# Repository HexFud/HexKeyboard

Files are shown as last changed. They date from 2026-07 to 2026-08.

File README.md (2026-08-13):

# 9-key macropad + encoder + OLED

Homemade macropad: 9 keys in a 3x3 grid, a rotary encoder, and a 0.91" OLED screen. Every switch has its own RGB LED for backlighting, all chained together on a single data pin.

## Hardware

- Seeed XIAO RP2040
- 0.91 inch OLED display
- Rotary encoder with built-in push button
- 9x MX-Style switches, each with its own 1N4148 diode, 3x3 matrix
- 9x SK6812MINI-E LEDs daisy-chained for per-key backlighting

## Schematic

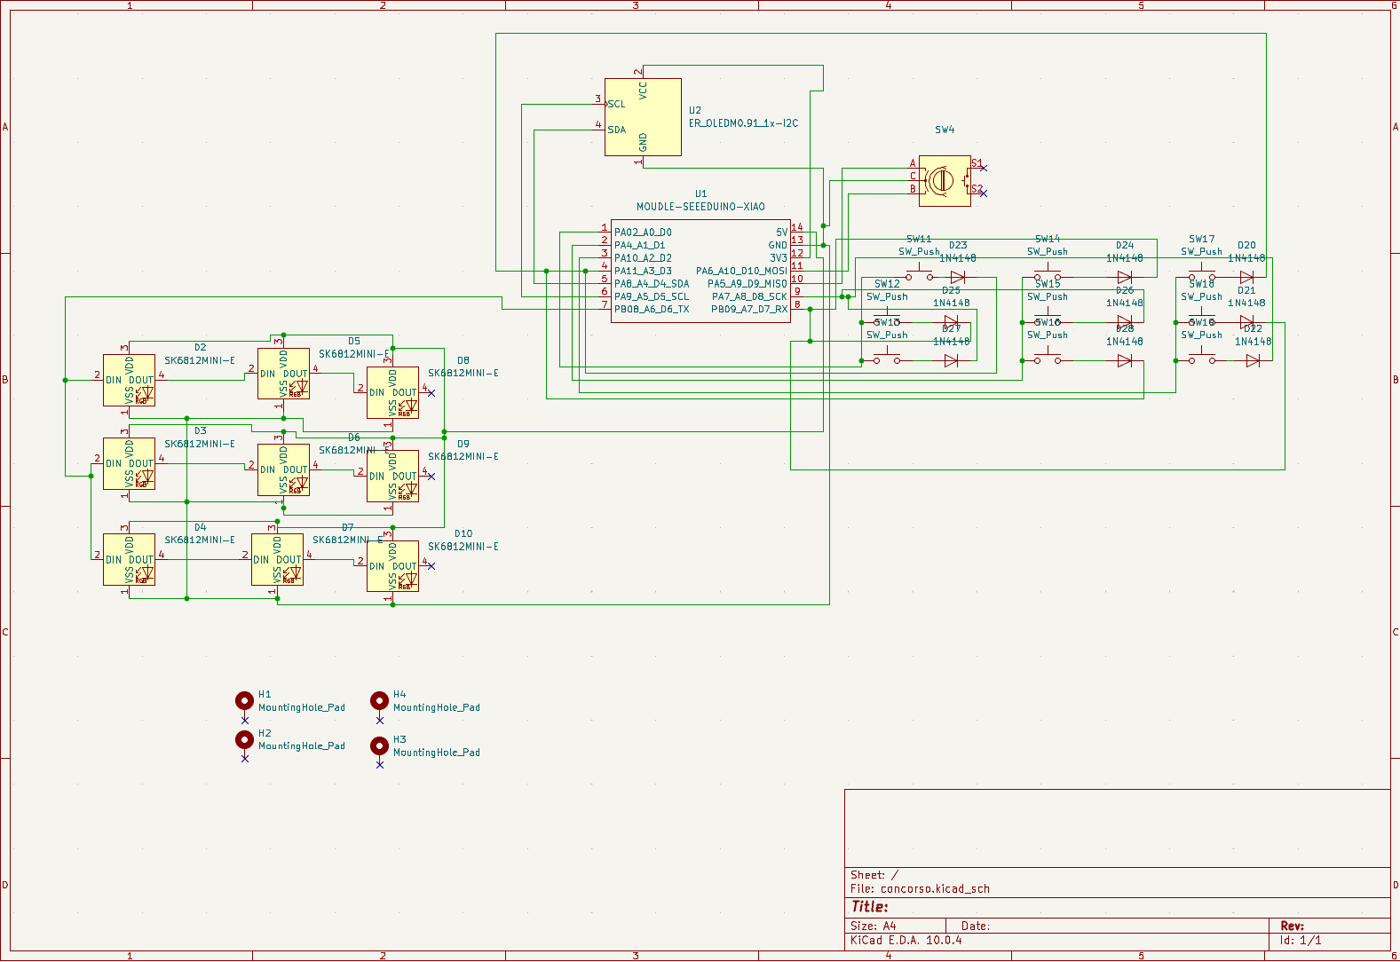
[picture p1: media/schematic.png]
Schematic


## PCB Render

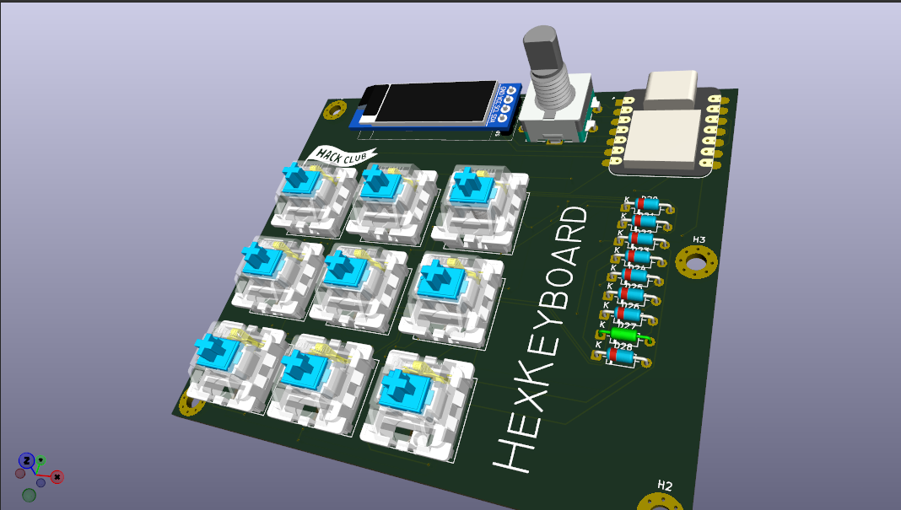
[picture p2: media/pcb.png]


## PCB

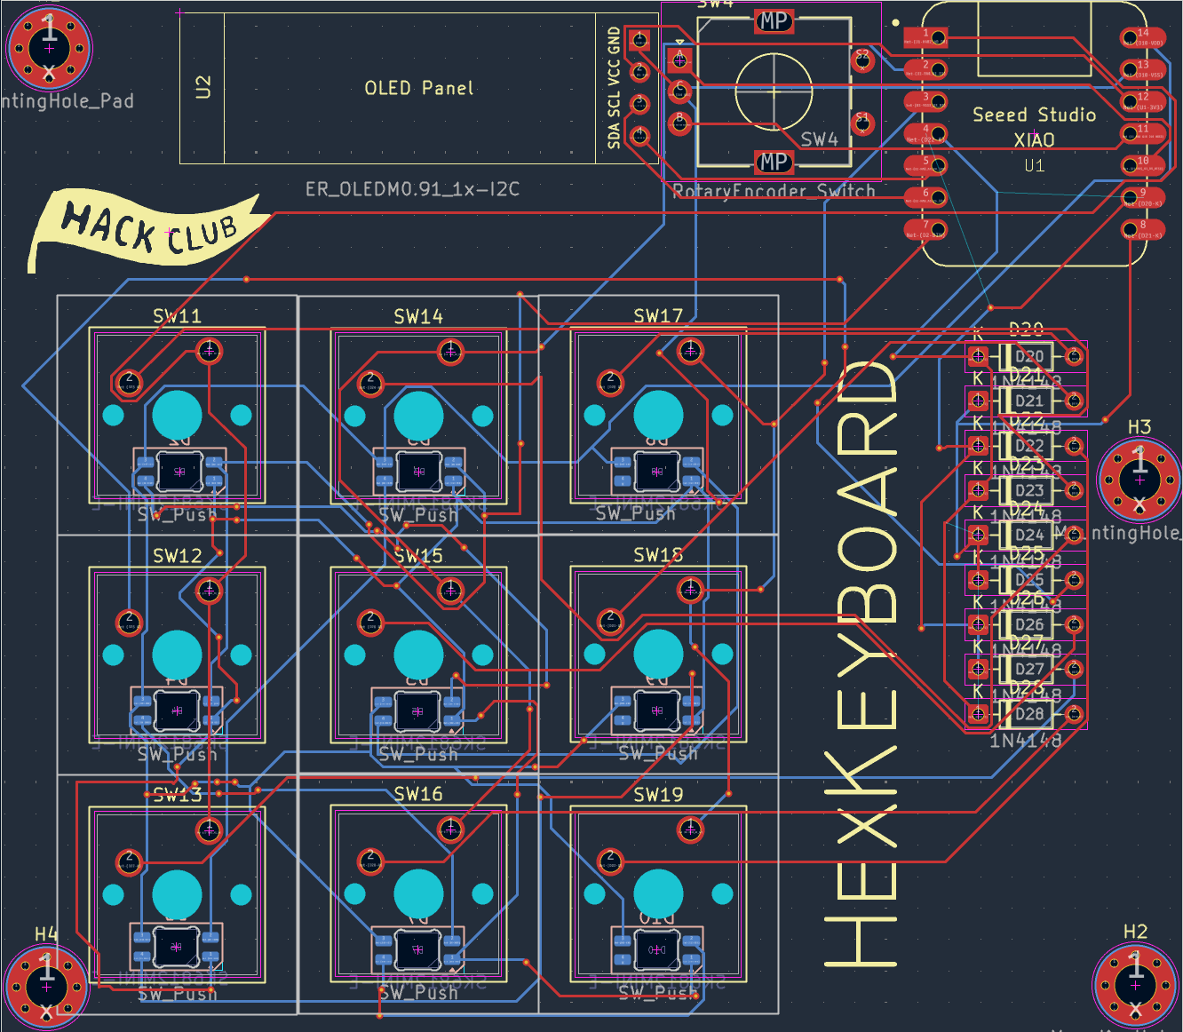
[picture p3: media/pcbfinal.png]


## Case

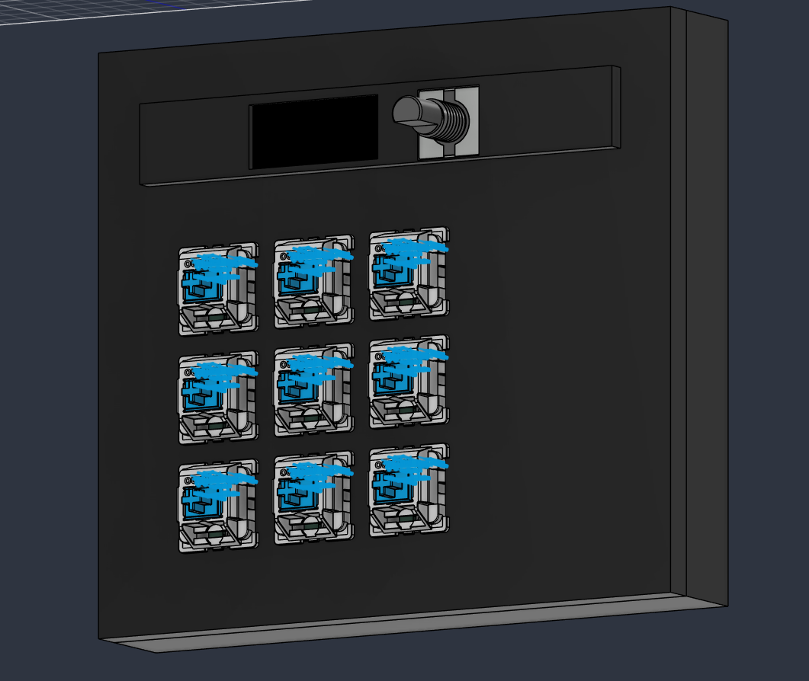
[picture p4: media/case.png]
Case


## Case Heated Inserts

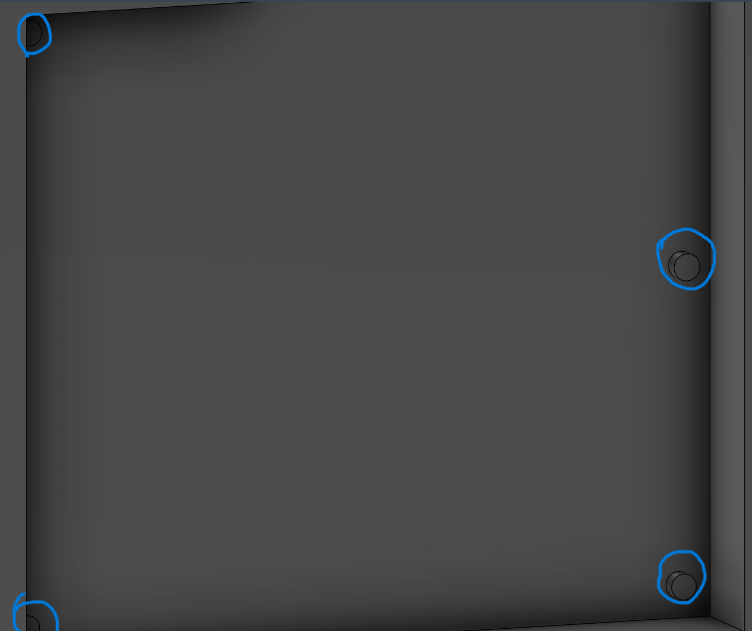
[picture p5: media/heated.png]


You can put heated inserts in the highlited zones and then screw the pcb in 

## BOM

| Qty | Part | Notes |
|---|---|---|
| 1 | Seeed XIAO RP2040 | main MCU |
| 1 | 0.91 inch OLED display | SSD1306 driver |
| 1 | Rotary encoder |
| 9 | Mechanical switches (MX-style) | |
| 9 | SK6812MINI-E RGB LED | daisy-chained backlight |
| 10 | 1N4148 diode | 9 for the key matrix + 1 for the encoder push button |
| 9 | Keycaps | |
| — | Case (top plate + bottom plate) | 3D printed |
| 8 | M3x16mm screws |
| 4 | M3x5x4mm heatset inserts |

## Firmware 

1. Flash CircuitPython onto the XIAO
2. Clone the KMK library (github.com/KMKfw/kmk_firmware) and copy its kmk/ folder onto the CIRCUITPY drive. Also install these CircuitPython libraries onto the board: adafruit_display_text, adafruit_displayio_ssd1306.
3. Copy boot.py and code.py to the root of the CIRCUITPY drive.
4. Reset the board (boot.py only runs on reset/power-up, not on save).

## What it does

- 9 programmable keys
- Encoder: function described below
- Screen: shows the progress bar of whatever track is playing 
- Per key RGB backlighting

## The music bar
 
I implemented a feature called music bar, if you are playing something in the background the duration of the media is showed on the display and you can controll it with the encoder. If you want to use this function you need to run the .py program in the firmware folder because otherwise the microcontroller doesn't know what is the device playing

## Note

The push button of the encoder is intentionally disconnected because there were no pins left on the microcontroller to connect it

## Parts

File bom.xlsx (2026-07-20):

Designator | Quantity | Value | Footprint | Description
U1 | 1 | Seeed Studio XIAO RP2040 | XIAO_14pin_SMD_or_THT | Main microcontroller based on the RP2040 chip
DISP1 | 1 | OLED 0.91 inch | 4-pin_Header_2.54mm | I2C OLED Display Module 128x32 (SSD1306 driver)
RE1 | 1 | Rotary Encoder EC11 | EC11_5-pin_THT | Rotary encoder with integrated push button
SW1-SW9 | 9 | Mechanic Switch MX-Style | Cherry_MX_3-pin_or_5-pin | IMPORTANT: Switches must have the appropriate slot/hole (SMD LED slot) on the bottom side to allow light from the SMD LED soldered on the PCB to pass through.
D1-D9 | 9 | Diode 1N4148 | SOD-123 (SMD) o DO-35 (THT) | Signal diode for 3x3 matrix wiring (anti-ghosting/NKRO).
LED1-LED9 | 9 | SK6812MINI-E | SMD_3228_Reverse_Mount | Addressable RGB LED. Mounted upside down on the back of the PCB; the light passes through a hole in the PCB and then through the switch.
KEYCAP1-9 | 9 | Keycaps MX | 1U | Keycaps compatible with MX switches. Translucent (pudding or clear) keycaps are recommended for the best LED lighting.

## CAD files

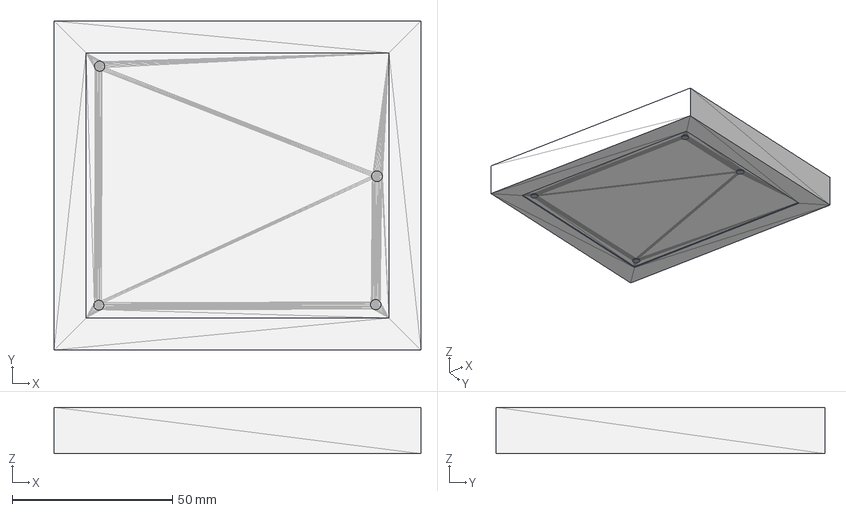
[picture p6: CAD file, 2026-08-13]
production/bottom.step
114.6 x 102.8 x 14.5 mm

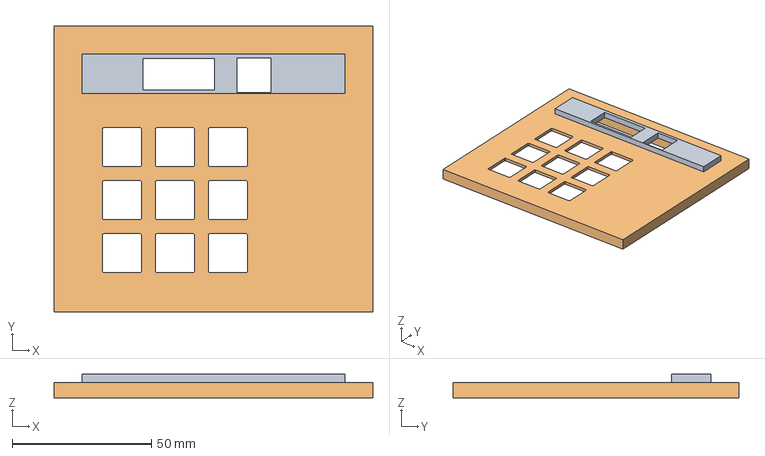
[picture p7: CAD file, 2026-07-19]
production/Top.step
114.6 x 102.8 x 8.50 mm

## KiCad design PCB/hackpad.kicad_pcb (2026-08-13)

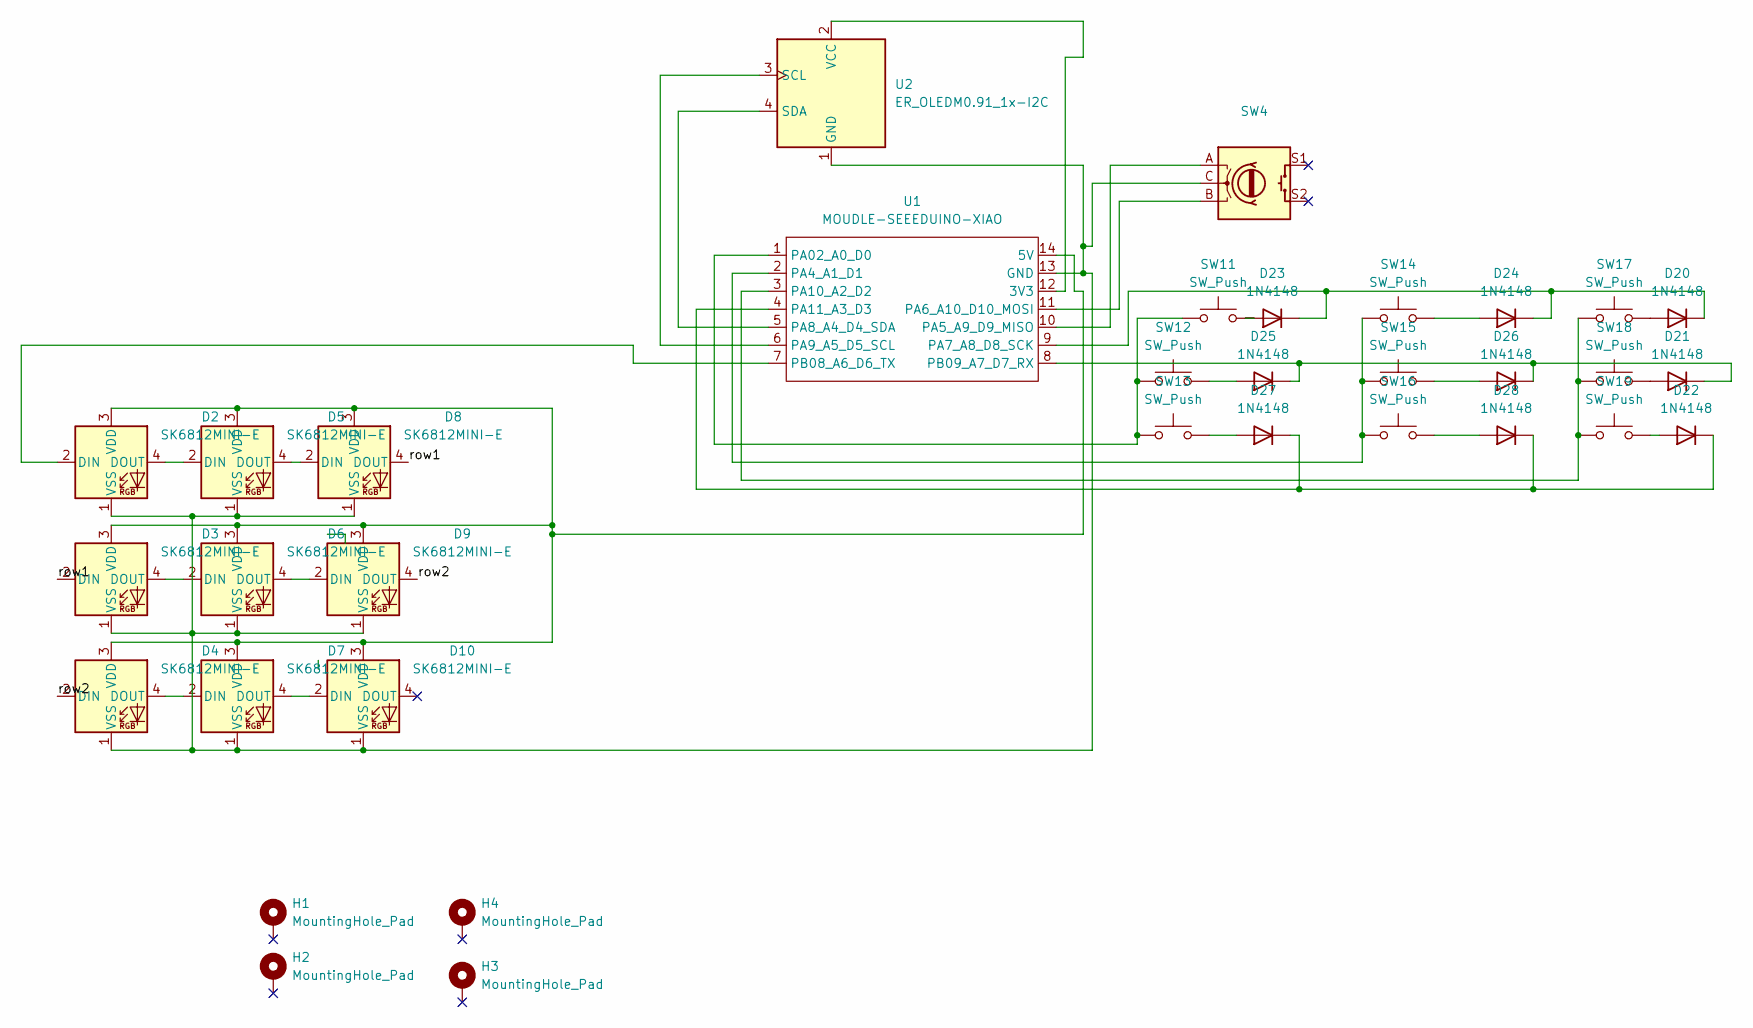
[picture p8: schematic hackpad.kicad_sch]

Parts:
D2, D3, D4, D5, D6, D7, D8, D9, D10: SK6812MINI-E; LED_SK6812MINI-E_3.2x2.8mm_P1.5mm_ReverseMount
D20, D21, D22, D23, D24, D25, D26, D27, D28: 1N4148; D_DO-35_SOD27_P7.62mm_Horizontal
H1, H2, H3, H4: MountingHole_Pad; MountingHole_3.2mm_M3_Pad_Via
SW4: RotaryEncoder_Switch; RotaryEncoder_Alps_EC11E-Switch_Vertical_H20mm
SW11, SW12, SW13, SW14, SW15, SW16, SW17, SW18, SW19: SW_Push; SW_Cherry_MX_1.00u_PCB
U1: MOUDLE-SEEEDUINO-XIAO; XIAO-Generic-Hybrid-14P-2.54-21X17.8MM
U2: ER_OLEDM0.91_1x-I2C; SSD1306-0.91-OLED-4pin-128x32

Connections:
/row1: D3.2 (DIN), D8.4 (DOUT)
/row2: D4.2 (DIN), D9.4 (DOUT)
unnamed: D2.2 (DIN), U1.7 (PB08_A6_D6_TX)
unnamed: D2.4 (DOUT), D5.2 (DIN)
unnamed: D3.4 (DOUT), D6.2 (DIN)
unnamed: D4.4 (DOUT), D7.2 (DIN)
unnamed: D5.4 (DOUT), D8.2 (DIN)
unnamed: D6.4 (DOUT), D9.2 (DIN)
unnamed: D7.4 (DOUT), D10.2 (DIN)
unnamed: D2.3 (VDD), D3.3 (VDD), D4.3 (VDD), D5.3 (VDD), D6.3 (VDD), D7.3 (VDD), D8.3 (VDD), D9.3 (VDD), D10.3 (VDD), U1.14 (5V)
unnamed: D2.1 (VSS), D3.1 (VSS), D4.1 (VSS), D5.1 (VSS), D6.1 (VSS), D7.1 (VSS), D8.1 (VSS), D9.1 (VSS), D10.1 (VSS), SW4.C, U1.13 (GND), U2.1 (GND)
unnamed: D20.2 (A), SW17.2
unnamed: D20.1 (K), D23.1 (K), D24.1 (K), U1.9 (PA7_A8_D8_SCK)
unnamed: D21.2 (A), SW18.2
unnamed: D21.1 (K), D25.1 (K), D26.1 (K), U1.8 (PB09_A7_D7_RX)
unnamed: D22.2 (A), SW19.2
unnamed: D22.1 (K), D27.1 (K), D28.1 (K), U1.4 (PA11_A3_D3)
unnamed: D23.2 (A), SW11.2
unnamed: D24.2 (A), SW14.2
unnamed: D25.2 (A), SW12.2
unnamed: D26.2 (A), SW15.2
unnamed: D27.2 (A), SW13.2
unnamed: D28.2 (A), SW16.2
unnamed: U1.12 (3V3), U2.2 (VCC)
unnamed: SW11.1, SW12.1, SW13.1, U1.1 (PA02_A0_D0)
unnamed: SW14.1, SW15.1, SW16.1, U1.2 (PA4_A1_D1)
unnamed: SW4.A, U1.10 (PA5_A9_D9_MISO)
unnamed: SW4.B, U1.11 (PA6_A10_D10_MOSI)
unnamed: U1.5 (PA8_A4_D4_SDA), U2.4 (SDA)
unnamed: U1.6 (PA9_A5_D5_SCL), U2.3 (SCL)
unnamed: SW17.1, SW18.1, SW19.1, U1.3 (PA10_A2_D2)

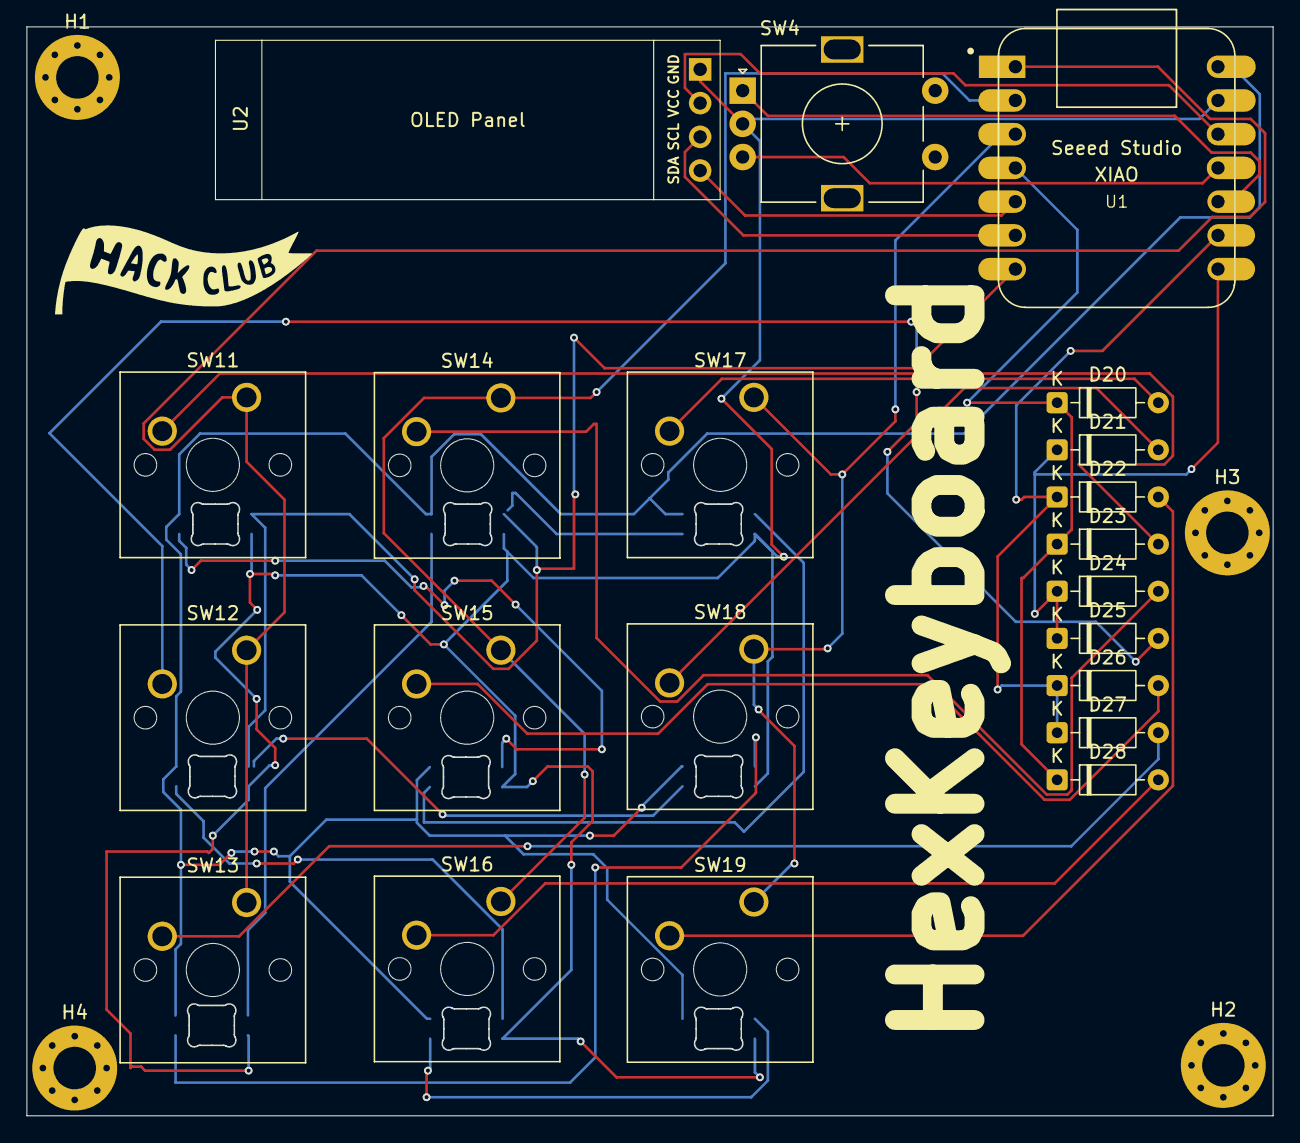
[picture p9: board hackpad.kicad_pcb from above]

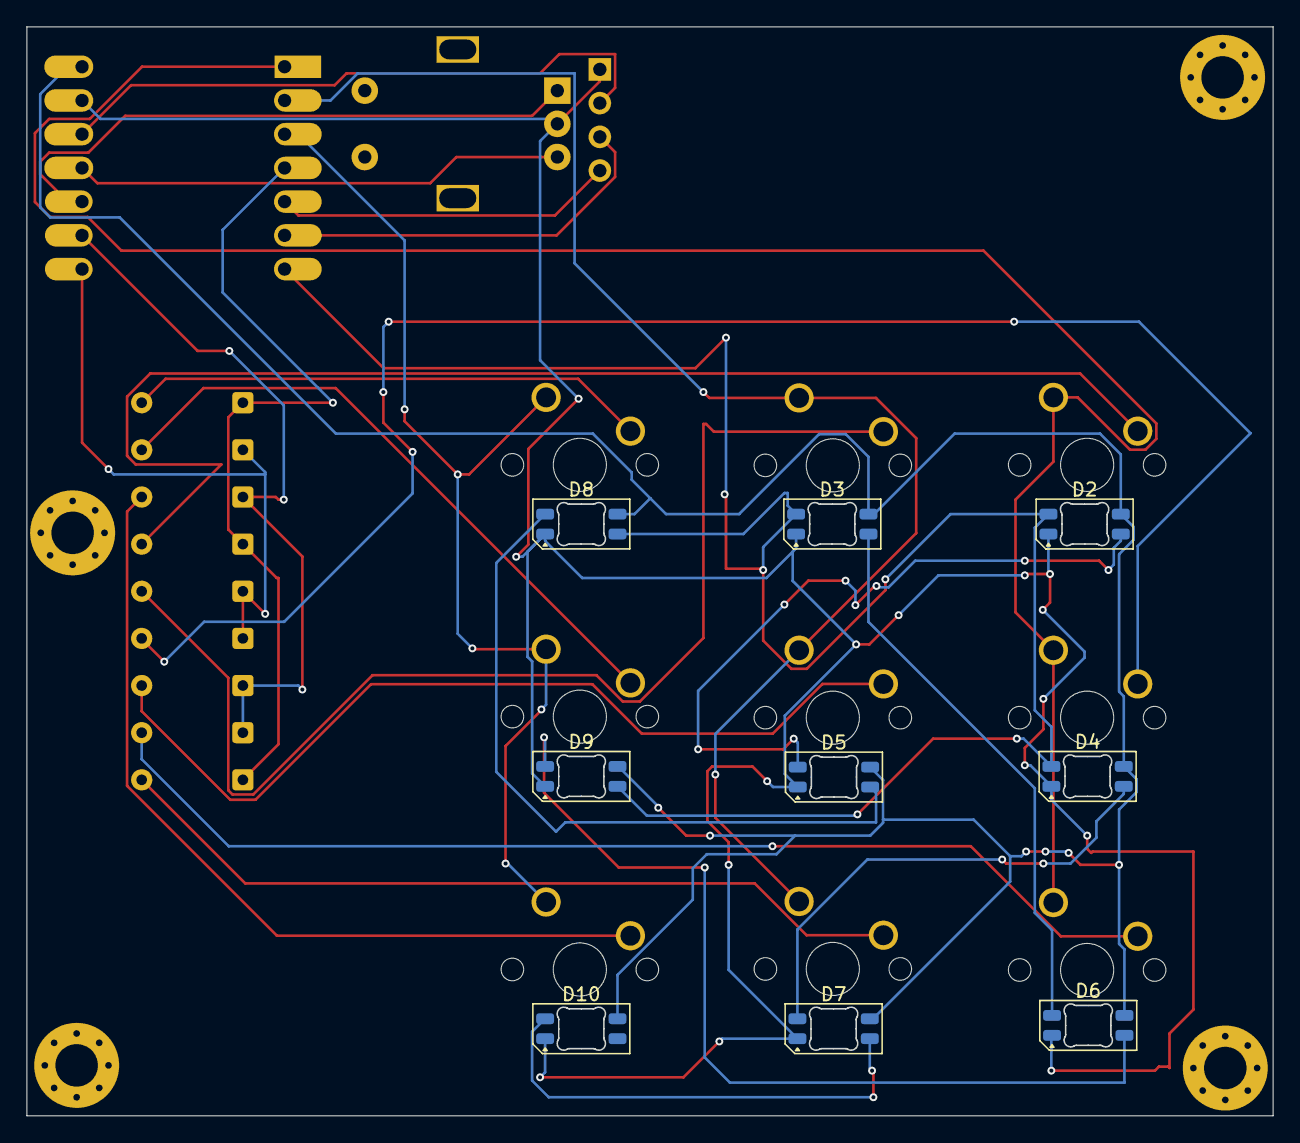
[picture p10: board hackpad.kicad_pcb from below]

Board: 2 copper layers, 93.8 x 82.0 mm, 34 parts (9 on the bottom side), 31 nets.

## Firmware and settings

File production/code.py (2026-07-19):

import time
import board
import busio
import displayio
import terminalio
import usb_hid

from adafruit_display_text import label
import adafruit_displayio_ssd1306

from kmk.kmk_keyboard import KMKKeyboard
from kmk.keys import KC
from kmk.matrix import DiodeOrientation
from kmk.modules import Module
from kmk.modules.encoder import EncoderHandler
from kmk.extensions.rgb import RGB

keyboard = KMKKeyboard()

# ---- matrix: pin confermati dal netlist ----
# righe = D0,D1,D2 -- colonne = D3,D7,D8
keyboard.row_pins = (board.D0, board.D1, board.D2)
keyboard.col_pins = (board.D3, board.D7, board.D8)
keyboard.diode_orientation = DiodeOrientation.ROW2COL

# il pulsante dell'encoder e' scollegato (D13 rimosso, S1/S2 unconnected
# nel netlist), quindi la matrice e' solo i 9 switch reali.
# ordine fisico reale sul PCB (riga per riga, sinistra->destra):
#   riga D0: SW11(col D3), SW12(col D7), SW13(col D8)
#   riga D1: SW14(col D7), SW15(col D8), SW16(col D3)  -- occhio, non in ordine elettrico!
#   riga D2: SW17(col D3), SW18(col D7), SW19(col D8)
keyboard.keymap = [
    [
        KC.N1,  KC.N2,  KC.N3,    # riga D0: col D3, D7, D8 = SW11, SW12, SW13
        KC.N6,  KC.N4,  KC.N5,    # riga D1: col D3, D7, D8 = SW16, SW14, SW15
        KC.N7,  KC.N8,  KC.N9,    # riga D2: col D3, D7, D8 = SW17, SW18, SW19
    ]
]

# ---- encoder: ruotandolo avanti/indietro cerca nel brano ----
# nessun pulsante gestito
encoder_handler = EncoderHandler()
encoder_handler.pins = ((board.D9, board.D10, None),)  # (A, B, pulsante=None)
encoder_handler.map = [((KC.MRWD, KC.MFFD),)]
keyboard.modules.append(encoder_handler)

# ---- retroilluminazione, 9 SK6812 in catena ----
rgb = RGB(pixel_pin=board.D10, num_pixels=9, val_limit=100)
keyboard.extensions.append(rgb)

# ---- OLED ----
# SDA = D4 = PA08, SCL = D5 = PA09 -- confermati dalle etichette sullo schematic
displayio.release_displays()
i2c = busio.I2C(board.D5, board.D4)  # SCL, SDA
display_bus = displayio.I2CDisplay(i2c, device_address=0x3C)
display = adafruit_displayio_ssd1306.SSD1306(display_bus, width=128, height=32)

splash = displayio.Group()
display.root_group = splash

title_label = label.Label(terminalio.FONT, text="No player", x=0, y=6)
bar_label = label.Label(terminalio.FONT, text="", x=0, y=20)
splash.append(title_label)
splash.append(bar_label)


def draw_bar(percent, width=16):
    filled = int(max(0, min(100, percent)) / 100 * width)
    return "#" * filled + "-" * (width - filled)


# ---- raw HID: deve essere dichiarato in boot.py, qui lo recuperiamo ----
raw_hid = None
for device in usb_hid.devices:
    if getattr(device, "usage_page", None) == 0xFF60 and getattr(device, "usage", None) == 0x61:
        raw_hid = device
        break

media_state = {"playing": False, "track_percent": 0, "volume_percent": 0, "title": ""}


class MediaDisplay(Module):
    """Legge i pacchetti raw HID dal companion script e aggiorna l'OLED.
    Gestisce anche la finestra 'mostra il volume' dopo il click dell'encoder."""

    def __init__(self):
        self.volume_view_until = 0
        self.last_hid_packet = 0
        self.hid_timeout_ms = 3000
        self.volume_view_ms = 2000
        self.last_update = 0

    def during_bootup(self, keyboard):
        return

    def before_matrix_scan(self, keyboard):
        now = time.monotonic() * 1000

        # click sull'encoder -> mostra il volume per un po'
        for key in keyboard.keys_pressed:
            if key == KC.MUTE:
                self.volume_view_until = now + self.volume_view_ms

        self._read_hid(now)

        # aggiorna l'OLED al massimo 10 volte al secondo, non ad ogni scan
        if now - self.last_update > 100:
            self._update_oled(now)
            self.last_update = now

        return

    def after_matrix_scan(self, keyboard):
        return

    def before_hid_send(self, keyboard):
        return

    def after_hid_send(self, keyboard):
        return

    def on_powersave_enable(self, keyboard):
        return

    def on_powersave_disable(self, keyboard):
        return

    def _read_hid(self, now):
        global raw_hid
        if raw_hid is None:
            return
        report = raw_hid.get_last_received_report()
        if not report:
            return
        media_state["playing"] = bool(report[0])
        media_state["track_percent"] = report[1]
        media_state["volume_percent"] = report[2]
        raw_title = bytes(report[3:19]).split(b"\x00")[0]
        media_state["title"] = raw_title.decode("utf-8", "ignore")
        self.last_hid_packet = now

    def _update_oled(self, now):
        hid_alive = (now - self.last_hid_packet) < self.hid_timeout_ms
        show_volume = now < self.volume_view_until

        if show_volume:
            title_label.text = "Volume"
            bar_label.text = draw_bar(media_state["volume_percent"])
        elif not hid_alive:
            title_label.text = "No player"
            bar_label.text = ""
        else:
            title_label.text = (media_state["title"] or "Playing")[:16]
            if media_state["playing"]:
                bar_label.text = draw_bar(media_state["track_percent"])
            else:
                bar_label.text = "paused"


keyboard.modules.append(MediaDisplay())

if __name__ == "__main__":
    keyboard.go()

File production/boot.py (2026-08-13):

"""
boot.py gira PRIMA di code.py, una volta sola all'accensione/reset.
Serve a dichiarare un device USB HID "raw" in piu' rispetto a quello
standard della tastiera, cosi' il companion script sul PC puo' mandare
dati (stato musica, volume) senza interferire con la tastiera normale.

Dopo aver modificato boot.py serve un reset della scheda (non basta
salvare code.py) perche' i device USB si configurano solo all'avvio.
"""

import usb_hid

RAW_HID_REPORT_DESCRIPTOR = bytes((
    0x06, 0x60, 0xFF,  # Usage Page (Vendor Defined 0xFF60)
    0x09, 0x61,        # Usage (0x61)
    0xA1, 0x01,        # Collection (Application)
    0x15, 0x00,        #   Logical Minimum (0)
    0x26, 0xFF, 0x00,  #   Logical Maximum (255)
    0x75, 0x08,        #   Report Size (8)
    0x95, 0x20,        #   Report Count (32) -- deve combaciare col companion script
    0x09, 0x62,        #   Usage (0x62)
    0x81, 0x02,        #   Input (Data,Var,Abs)
    0x95, 0x20,        #   Report Count (32)
    0x09, 0x63,        #   Usage (0x63)
    0x91, 0x02,        #   Output (Data,Var,Abs)
    0xC0,              # End Collection
))

raw_hid_device = usb_hid.Device(
    report_descriptor=RAW_HID_REPORT_DESCRIPTOR,
    usage_page=0xFF60,
    usage=0x61,
    report_ids=(0,),
    in_report_lengths=(32,),
    out_report_lengths=(32,),
)

usb_hid.enable(
    (usb_hid.Device.KEYBOARD, usb_hid.Device.CONSUMER_CONTROL, raw_hid_device)
)
